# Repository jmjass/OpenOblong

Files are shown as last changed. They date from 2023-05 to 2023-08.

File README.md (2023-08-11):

# OpenRectangleCubsMod
Custom PCBs for a RP2040 powered rectangle controller.

Modified version of https://github.com/Armastardo/OpenRectangle that decreases size of the PCB and changes button layout to accomodate.

Original Dimensions: 339.13mm x 141.22mm

Modified Dimensions: 282.7mm x 136.22mm

Case Dimensions: 296mm x 154.4mm (~11.65" x ~6.08")

(Thickness of the case varies based on thickness of acrylic layers)

## Part Links:

Case Standoffs: 

https://www.aliexpress.us/item/2251832708378430.html?gatewayAdapt=glo2usa4itemAdapt&_randl_shipto=US

Calculate the thickness of your case and order standoffs about 1mm shorter than the case.

Case Screws: 
https://www.amazon.com/dp/B0798227SK?psc=1&ref=ppx_yo2ov_dt_b_product_details

Any M2 screws will work, I got these because I wanted black ones that are flush with the case.

Acrylic:

https://houstonacrylic.com/

There is a huge variety of colors and different designs of acrylic offered by these guys but they are a bit more expensive than other places. Also I had to pay about $17 for shipping so be sure to account for shipping costs in budget. If you order a 12 x 19 inch sheet from here you are able to cut 3 layers out of it.

If you are trying to make it as cheap as possible, I would recommend shopping around for clear acrylic because clear seemed to be the cheapest when I was looking. Here are a couple different thickness ones from amazon that I found:

1/8" For Top/Bottom Layers + PCB Layers on Aluminum Switchplate Design: https://www.amazon.com/dp/B09XR8NB28?psc=1&ref=ppx_yo2ov_dt_b_product_details

Acrylic Switchplate (.06"): https://www.amazon.com/dp/B09LTYDYKP?psc=1&ref=ppx_yo2ov_dt_b_product_details

PCB Layer/Hotswap Cutout Layer on Acylic Switchplate Design (.08"): https://www.amazon.com/dp/B09N3PN8PG?ref=ppx_yo2ov_dt_b_product_details&th=1

I recommend doing some searching on your own as there may be different options that are cheaper. 8" x 12" works the best for cutting 1 panel per sheet and for getting mroe than 1 panel per sheet you need multiples of 6.315" x 12". For example, 12" x 19" can get you 3 layers with very little margin of error or 12" x 21" would get you 3 layers way more comfortable although you are unlikely to find this size and would more commonly find 12" x 24"

3.5mm M1.6 PCB Standoffs:

https://www.ebay.com/itm/185215966272?var=692974532230

3mm M1.6 PCB Screws:

https://www.ebay.com/itm/183908369734

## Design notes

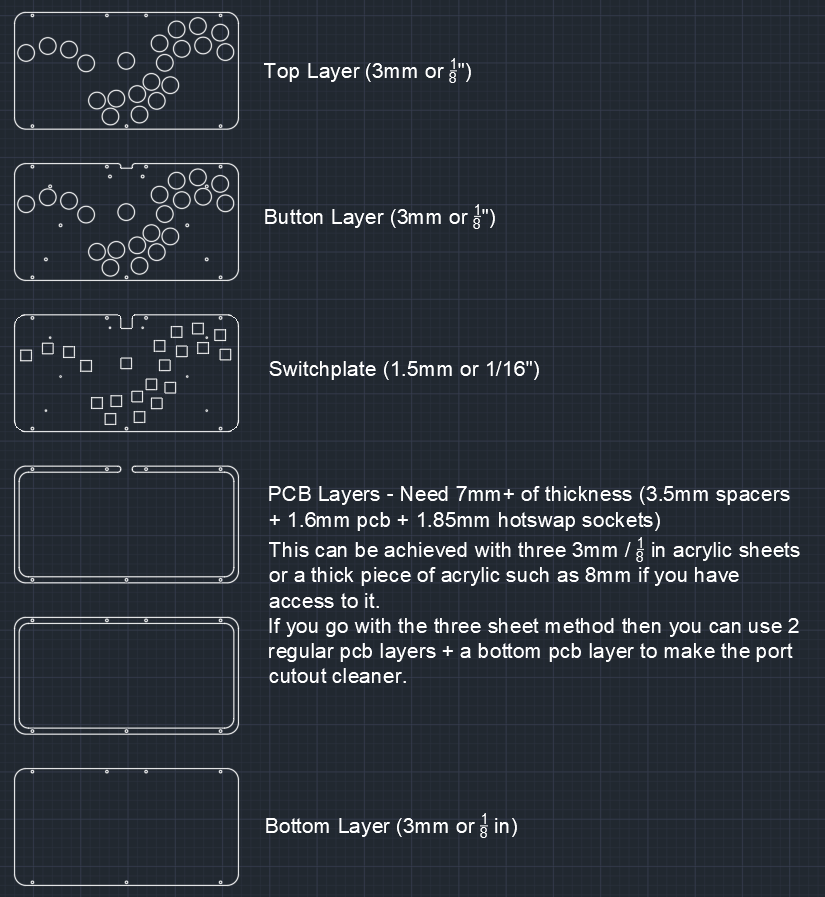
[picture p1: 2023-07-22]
CubsCase/ExpandedCase.png

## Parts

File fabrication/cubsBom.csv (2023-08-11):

Comment | Designator | Footprint | LCSC Part #
1uF | C1,C2,C4,C10 | Capacitor_SMD:C_0402_1005Metric | C52923
100nF | C3,C5,C6,C11,C12,C13,C14,C15,C16,C17 | Capacitor_SMD:C_0402_1005Metric | C1525
10uF | C9 | Capacitor_SMD:C_0402_1005Metric | C15525
22pF | C7,C8 | Capacitor_SMD:C_0402_1005Metric | C1555
Schottky Diode | D1,D2 | qw-footprints:CUSTOM D_SOD-123 | C8598
Fuse_Small | F1 | Fuse:Fuse_1206_3216Metric | C70069
USB C Connector | J1 | qw-footprints:TYPE-C_24P_QCHT | C456013
1M | R1 | Resistor_SMD:R_0603_1608Metric | C22935
5.1k | R2,R3 | Resistor_SMD:R_0402_1005Metric | C23186
5.6k | R5 | Resistor_SMD:R_0603_1608Metric | C23189
10k 0603 | R6 | Resistor_SMD:R_0603_1608Metric | C25804
10k 0402 | R4, R7 | Resistor_SMD:R_0402_1005Metric | C25744
27 | R8,R9 | Resistor_SMD:R_0603_1608Metric | C25190
1k | R10,R11 | Resistor_SMD:R_0402_1005Metric | C11702
Boot | SW1 | Button_Switch_SMD:SW_SPST_SKQG_WithStem | C318884
XC6206 | U1 | Package_TO_SOT_SMD:SOT-23 | C5446
USBLC6-2SC6 | U2 | Package_TO_SOT_SMD:SOT-23-6 | C5261088
RP2040 | U3 | qw-footprints:RP2040-QFN-56 | C2040
W25Q128JVS | U4 | Package_SO:SOIC-8_5.23x5.23mm_P1.27mm | C97521
12MHz | Y1 | Crystal:Crystal_SMD_3225-4Pin_3.2x2.5mm | C9002
PICO_LED | D3 | LED_SMD:LED_0805_2012Metric | C34499

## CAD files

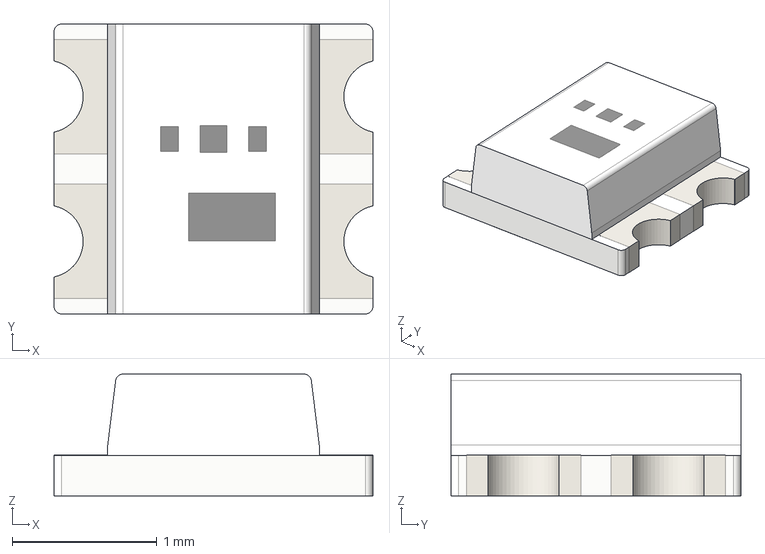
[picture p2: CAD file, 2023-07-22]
PCB Files/OpenOblong/marbastlib/3d/LED_WS2812_2020.step
2.20 x 2.00 x 0.842 mm

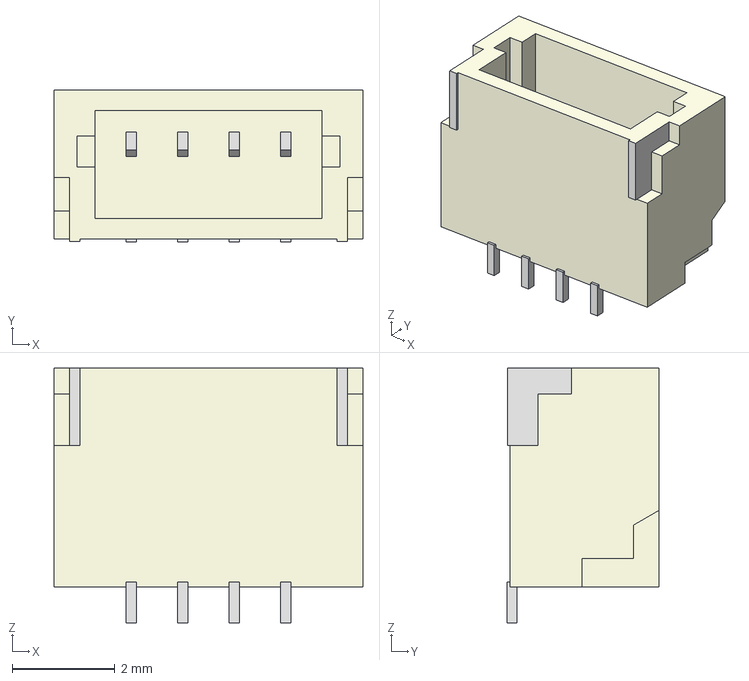
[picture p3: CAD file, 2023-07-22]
PCB Files/OpenOblongChocs/marbastlib/3d/CON_SM04B-SRSS-TB.step
6.00 x 2.96 x 4.95 mm

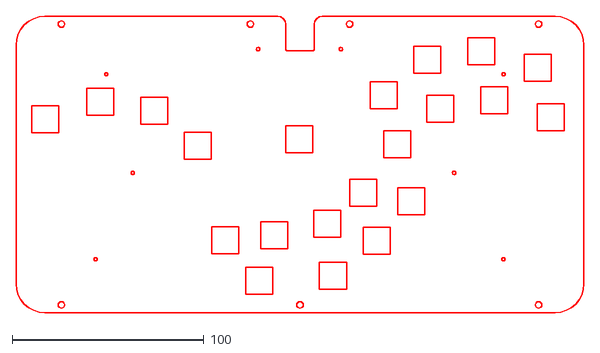
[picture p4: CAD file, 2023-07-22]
CubsCase/SwitchPlate14.1.dxf
296.0 x 154.4

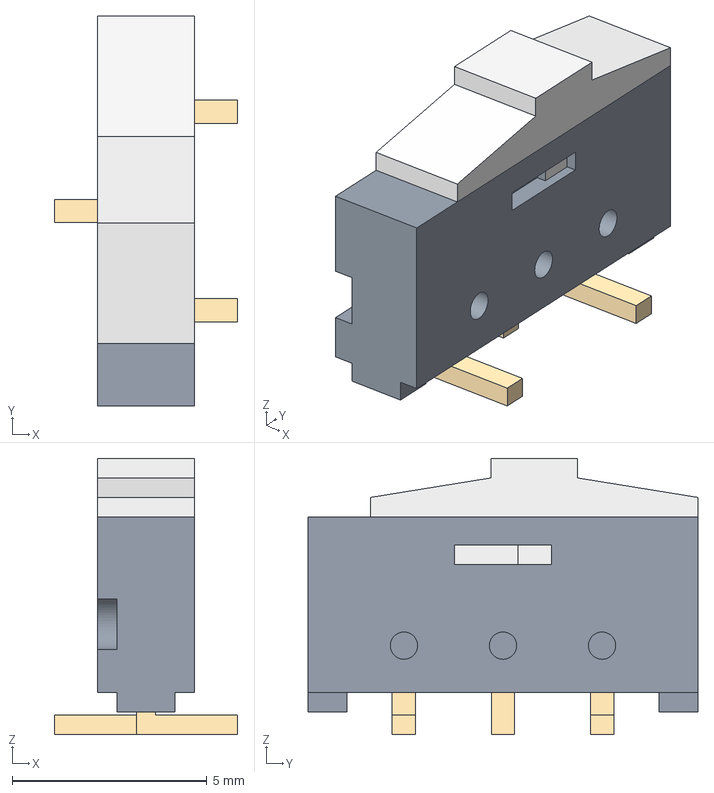
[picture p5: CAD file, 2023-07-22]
PCB Files/OpenOblong/marbastlib/3d/SW_ESP3020.step
4.70 x 10.0 x 7.08 mm

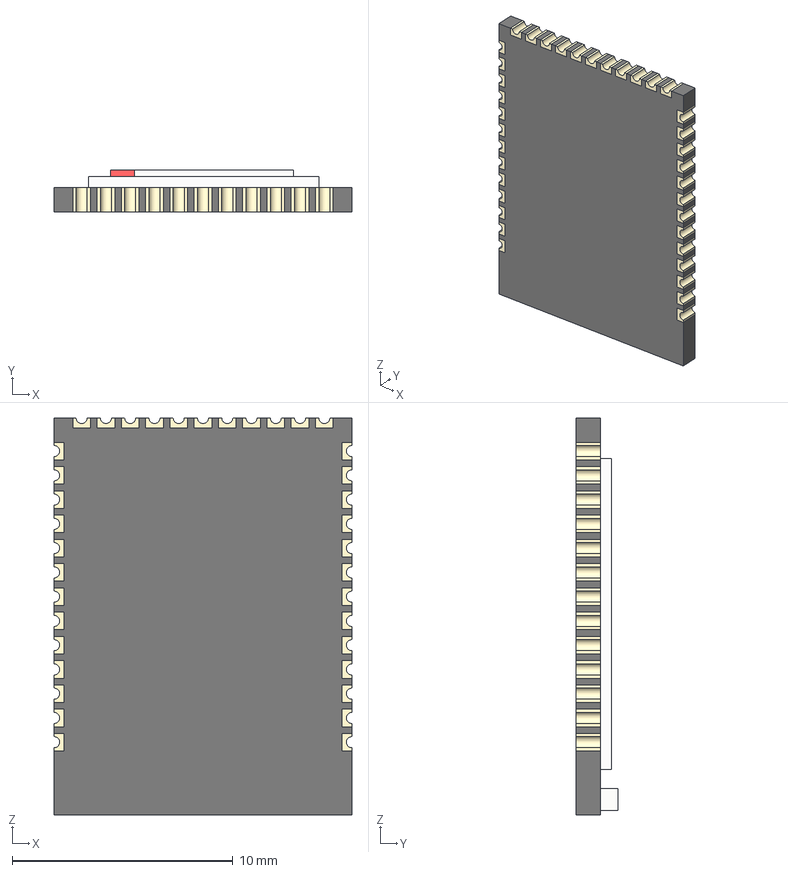
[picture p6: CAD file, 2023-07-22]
PCB Files/OpenOblongChocs/marbastlib/3d/holyiot_18010_nRF52840.step
13.5 x 1.92 x 18.0 mm

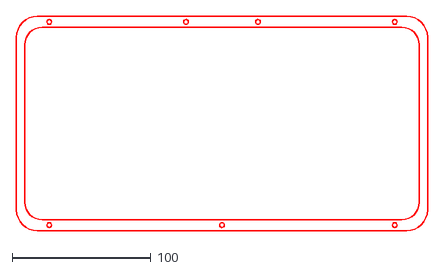
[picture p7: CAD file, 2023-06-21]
CubsCase/BottomPCBLayer.dxf
296.0 x 154.4

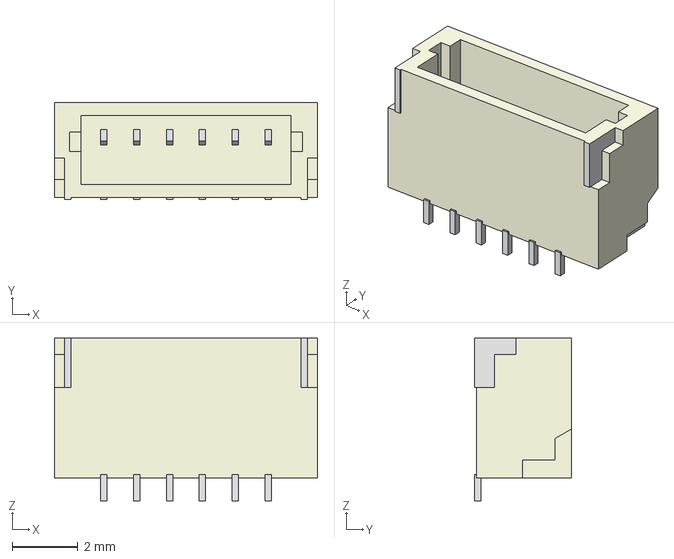
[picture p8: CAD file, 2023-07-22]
PCB Files/OpenOblongChocs/marbastlib/3d/CON_SM06B-SRSS-TB.step
8.00 x 2.96 x 4.95 mm

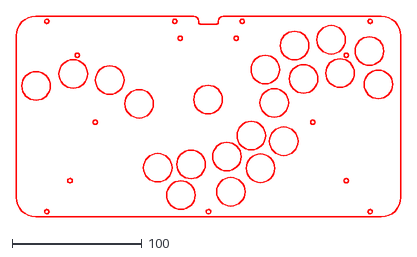
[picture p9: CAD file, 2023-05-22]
CubsCase/topLayer.dxf
296.0 x 154.4

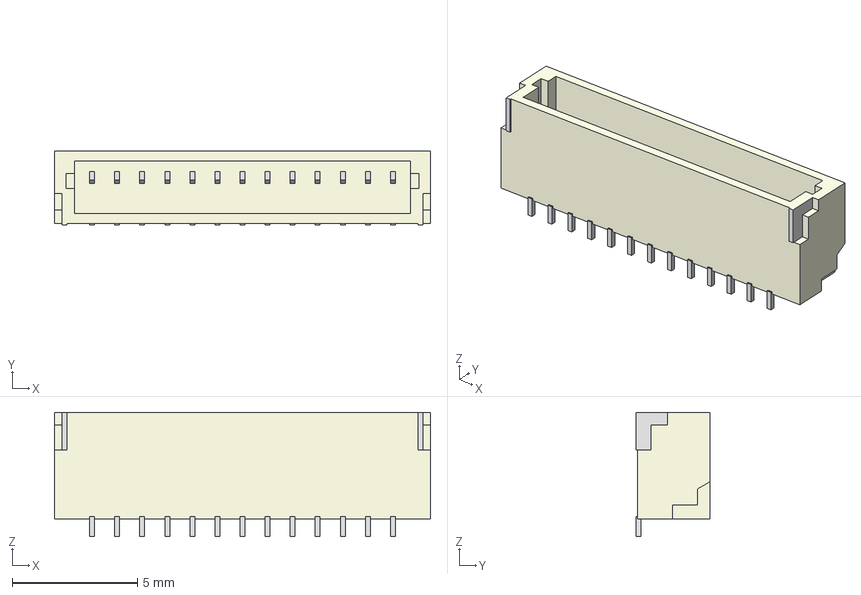
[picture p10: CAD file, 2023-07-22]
PCB Files/OpenOblong/marbastlib/3d/CON_SM13B-SRSS-TB.step
15.0 x 2.96 x 4.95 mm

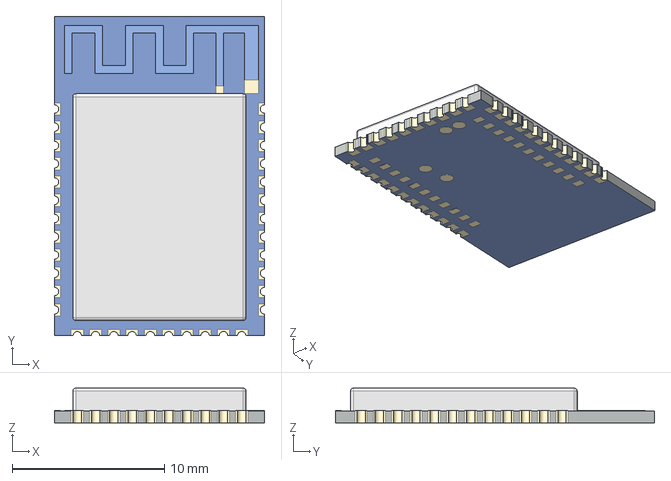
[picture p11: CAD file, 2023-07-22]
PCB Files/OpenOblongChocs/marbastlib/3d/moko_mk08a_nRF52840.step
13.8 x 21.0 x 2.29 mm

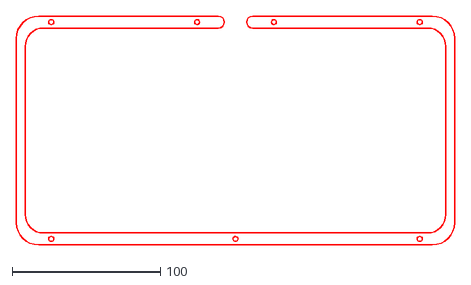
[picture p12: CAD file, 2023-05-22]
CubsCase/pcbLayer.dxf
296.0 x 154.4

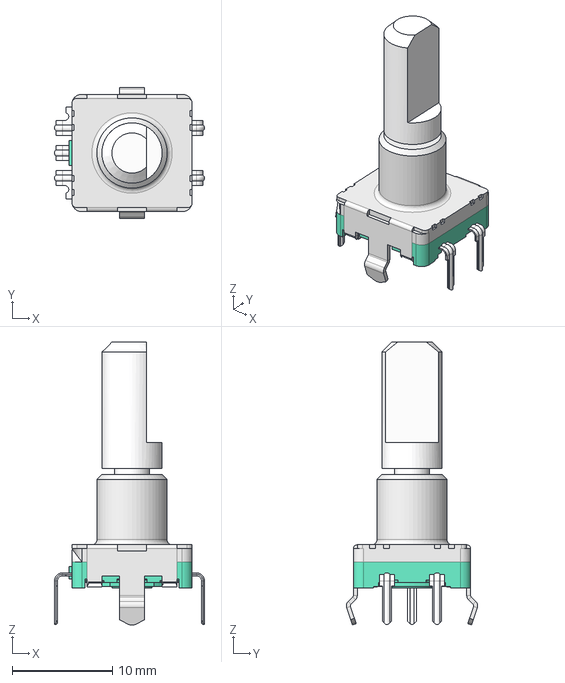
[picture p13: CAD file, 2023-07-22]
PCB Files/OpenOblong/marbastlib/3d/ROT_EC11E.step
14.9 x 13.1 x 28.2 mm

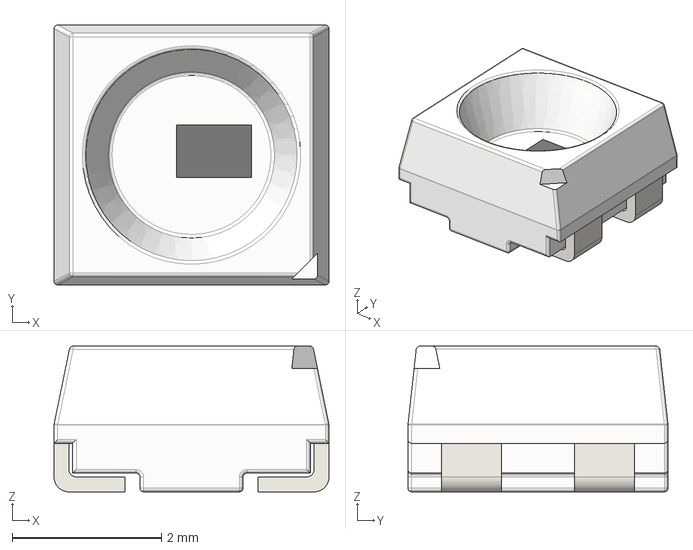
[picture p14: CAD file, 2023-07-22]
PCB Files/OpenOblongChocs/marbastlib/3d/LED_WS2812B-MINI.step
3.68 x 3.48 x 1.95 mm

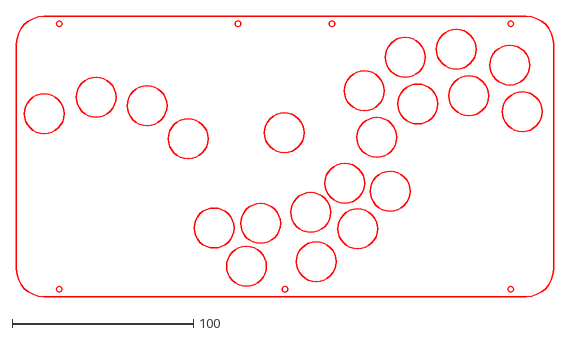
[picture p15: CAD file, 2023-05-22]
CubsCase/TopTop.dxf
296.0 x 154.4

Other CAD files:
CubsCase/expandedcase.dwg
CubsCase/LaserPrinting/SwitchPlateSpacerLayer.dwg
PCB Files/OpenOblong/marbastlib/3d/SW_SKHLLC.step
CubsCase/BottomLayer.dwg
CubsCase/BottomLayer.dxf
CubsCase/BottomPCBLayer.dwg
CubsCase/SwitchPlate14.1.dwg
CubsCase/TopTop.dwg
CubsCase/baseLayer.dxf
CubsCase/pcbLayer.dwg
CubsCase/topLayer.dwg
PCB Files/OpenOblong/marbastlib/3d/CON_BM02B-ACHSS.step
PCB Files/OpenOblong/marbastlib/3d/CON_MJ-4PP-9.step
PCB Files/OpenOblong/marbastlib/3d/CON_SM02B-SRSS-TB.step
PCB Files/OpenOblong/marbastlib/3d/CON_SM05B-SRSS-TB.step
PCB Files/OpenOblong/marbastlib/3d/CON_SM07B-SRSS-TB.step
PCB Files/OpenOblong/marbastlib/3d/CON_SM08B-SRSS-TB.step
PCB Files/OpenOblong/marbastlib/3d/CON_TYPE-C-31-M-12.step
PCB Files/OpenOblong/marbastlib/3d/CON_TYPE-C-31-M-14.step
PCB Files/OpenOblong/marbastlib/3d/Crystal_FA-128.step
PCB Files/OpenOblong/marbastlib/3d/HS_Kailh_Choc.step
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

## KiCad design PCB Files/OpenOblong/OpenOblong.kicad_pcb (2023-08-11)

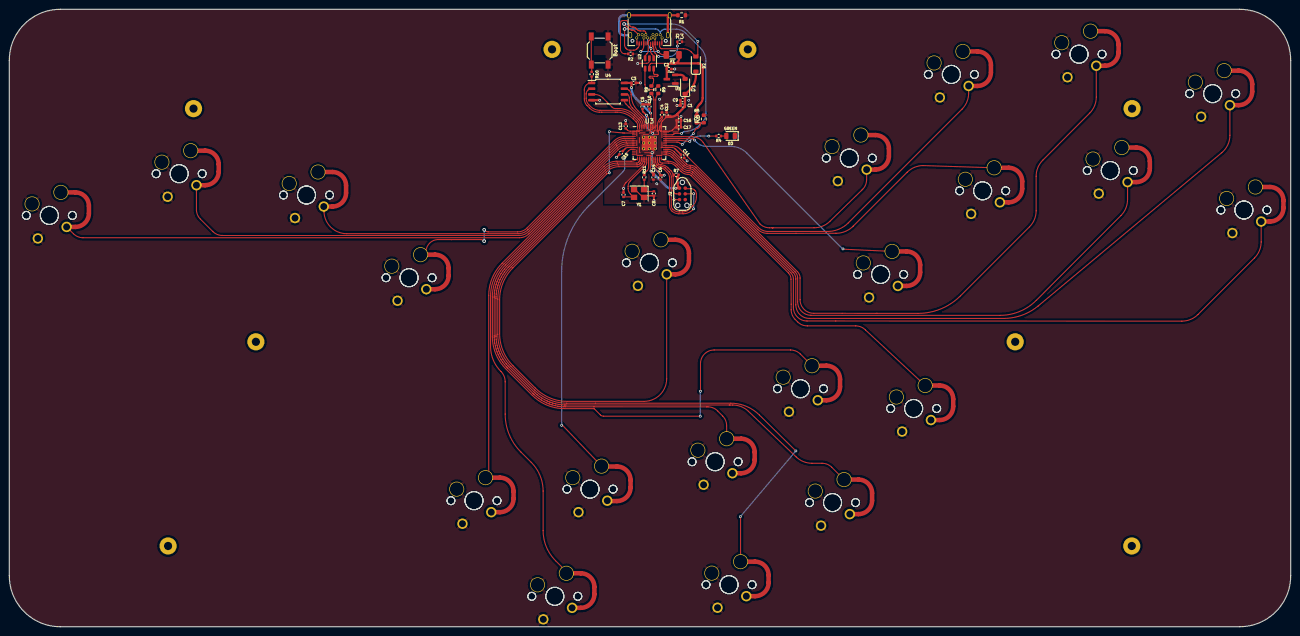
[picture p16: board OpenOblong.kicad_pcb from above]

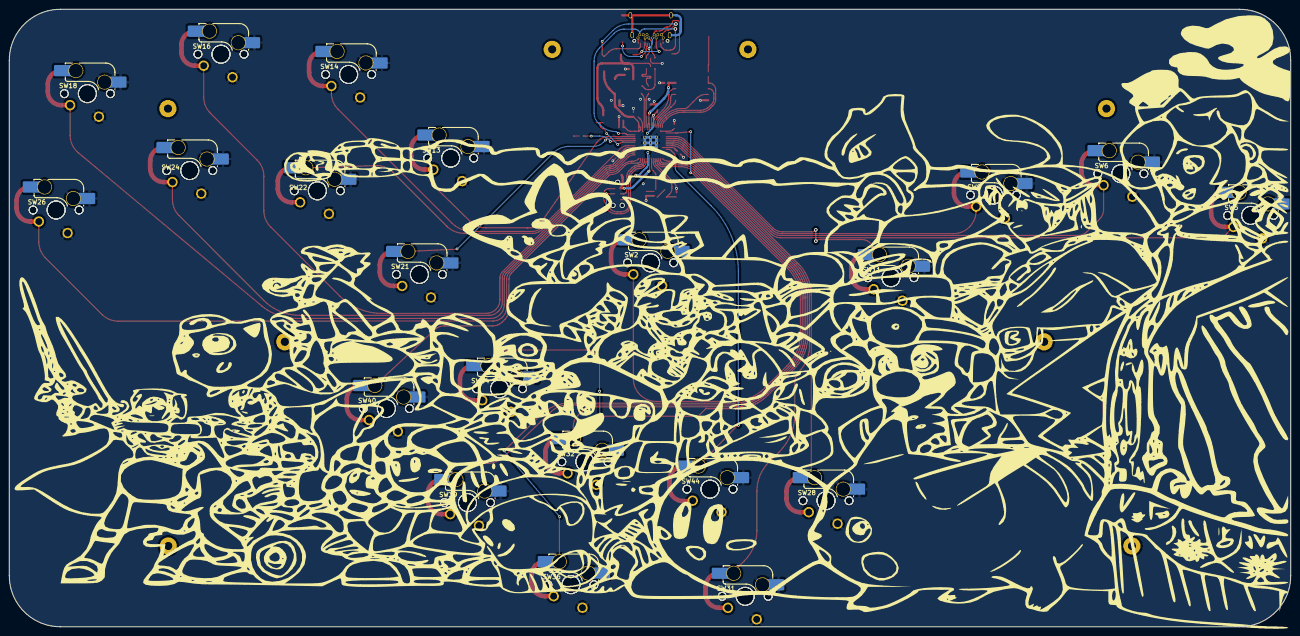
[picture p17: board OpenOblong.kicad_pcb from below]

Board: 2 copper layers, 282.7 x 136.2 mm, 90 parts (21 on the bottom side), 54 nets.

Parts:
C1, C2, C4, C10: 1uF; C_0402_1005Metric
C3, C5, C6, C11, C12, C13, C14, C15, C16, C17: 100nF; C_0402_1005Metric
C7, C8: 22pF; C_0402_1005Metric
C9: 10uF; C_0402_1005Metric
D1, D2: Schottky Diode; CUSTOM D_SOD-123
D3: GREEN; LED_0805_2012Metric
F1: 500 mA; Fuse_1206_3216Metric
H4, H5, H6, H7, H8, H9, H10, H11: MountingHole; MountingHole_2.2mm_M2_ISO14580_Pad
J1: USB C Connector; TYPE-C_24P_QCHT
J2: JTAG_TC2030; CON_TC2030_outlined
R1: 1M; R_0603_1608Metric
R2, R3: 5.1k; R_0402_1005Metric
R4, R7: 10k; R_0402_1005Metric
R5: 5.6k; R_0603_1608Metric
R6: 10k; R_0603_1608Metric
R8, R9: 27; R_0603_1608Metric
R10, R11: 1k; R_0402_1005Metric
SW1: Boot; SW_SPST_SKQG_WithStem
SW2, SW5, SW6, SW9, SW11, SW13, SW14, SW16, SW18, SW21, SW22, SW24, SW26, SW28, SW31, SW32, SW34, SW36, SW39, SW40, SW44: MX_SW_HS; SW_MX_HS_1u
SW3, SW4, SW7, SW8, SW10, SW12, SW15, SW17, SW19, SW20, SW23, SW25, SW27, SW29, SW30, SW33, SW35, SW37, SW38, SW41, SW45: MX_SW_solder; SW_MX_1u
U1: XC6206; SOT-23
U2: USBLC6-2SC6; SOT-23-6
U3: RP2040; RP2040-QFN-56
U4: W25Q128JVS; SOIC-8_5.23x5.23mm_P1.27mm
Y1: 12MHz; Crystal_SMD_3225-4Pin_3.2x2.5mm

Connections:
3vCable: D2.2 (A), J1.A2 (TX1+), J1.B2 (TX2+)
+1V1: C4.1, C5.1, C6.1, U3.23 (DVDD), U3.45 (VREG_VOUT), U3.50 (DVDD)
+3V3: C1.2, C3.1, C9.1, C10.1, C11.1, C12.1, C13.1, C14.1, C15.1, C16.1, C17.1, D1.1 (K), D2.1 (K), J2.1 (VCC), R7.1, U3.1 (IOVDD), U3.10 (IOVDD), U3.22 (IOVDD), U3.33 (IOVDD), U3.42 (IOVDD), U3.43 (ADC_AVDD), U3.44 (VREG_VIN), U3.48 (USB_VDD), U3.49 (IOVDD), U4.8 (VCC)
+5V: C2.2, F1.2, R5.1, U1.3 (VI), U2.5 (VBUS)
/D_+: R8.2, U3.47 (D+)
/D_-: R9.2, U3.46 (D-)
/XTAL_O: C8.2, R11.1, Y1.1
/~USB_BOOT: R10.1, SW1.2
A: SW38.1, SW39.2, U3.17 (GPIO14)
B: SW20.1, SW21.2, U3.38 (GPIO26/ADC0)
CS: R10.2, U3.56 (QSPI_SS_N), U4.1 (~CS)
C_DN: SW36.2, SW37.1, U3.18 (GPIO15)
C_LT: SW32.2, SW33.1, U3.16 (GPIO13)
C_RT: SW40.2, SW41.1, U3.27 (GPIO16)
C_UP: SW34.2, SW35.1, U3.15 (GPIO12)
D+: R8.1, U2.6 (I/O1)
D-: R9.1, U2.4 (I/O2)
DATA: J1.A11 (RX2+), J1.B11 (RX1+), U3.40 (GPIO28/ADC2)
DBUS+: J1.A6 (D+), J1.B6 (D+), U2.1 (I/O1)
DBUS-: J1.A7 (D-), J1.B7 (D-), U2.3 (I/O2)
DOWN: SW8.1, SW9.2, U3.5 (GPIO3)
GND: C1.1, C2.1, C3.2, C4.2, C5.2, C6.2, C7.1, C8.1, C9.2, C10.2, C11.2, C12.2, C13.2, C14.2, C15.2, C16.2, C17.2, D3.1 (K), J1.A1 (GND), J1.A12 (GND), J1.B1 (GND), J1.B12 (GND), J2.5 (GND), R1.1, R2.1, R3.2, R6.2, SW1.1, SW2.1, SW3.2, SW4.2, SW5.1, SW6.1, SW7.2, SW8.2, SW9.1, SW10.2, SW11.1, SW12.2, SW13.1, SW14.1, SW15.2, SW16.1, SW17.2, SW18.1, SW19.2, SW20.2, SW21.1, SW22.1, SW23.2, SW24.1, SW25.2, SW26.1, SW27.2, SW28.1, SW29.2, SW30.2, SW31.1, SW32.1, SW33.2, SW34.1, SW35.2, SW36.1, SW37.2, SW38.2, SW39.1, SW40.1, SW41.2, SW44.1, SW45.2, U1.1 (GND), U2.2 (GND), U3.19 (TESTEN), U3.57 (GND), U4.4 (GND), Y1.2, Y1.4
L: SW4.1, SW5.2, U3.7 (GPIO5)
LEFT: SW6.2, SW7.1, U3.6 (GPIO4)
LS: SW16.2, SW17.1, U3.31 (GPIO20)
M1: SW28.2, SW29.1, U3.8 (GPIO6)
M2: SW30.1, SW31.2, U3.9 (GPIO7)
M3: SW44.2, SW45.1, U3.11 (GPIO8)
MS: SW18.2, SW19.1, U3.29 (GPIO18)
unnamed: D1.2 (A), U1.2 (VO)
unnamed: D3.2 (A), R4.2
unnamed: F1.1, J1.A4 (VBUS), J1.A9 (VBUS), J1.B4 (VBUS), J1.B9 (VBUS)
unnamed: J1.A5 (CC1), R3.1
unnamed: J1.B5 (CC2), R2.2
unnamed: J1.S1 (SHIELD), R1.2
PICO_LED: R4.1, U3.37 (GPIO25)
QSPI_CLK: U3.52 (QSPI_SCLK), U4.6 (CLK)
R: SW12.1, SW13.2, U3.39 (GPIO27/ADC1)
RIGHT: SW10.1, SW11.2, U3.4 (GPIO2)
SD0: U3.53 (QSPI_SD0), U4.5 (DI(IO0))
SD1: U3.55 (QSPI_SD1), U4.2 (DO(IO1))
SD2: U3.54 (QSPI_SD2), U4.3 (IO2)
SD3: U3.51 (QSPI_SD3), U4.7 (IO3)
START: SW2.2, SW3.1, U3.2 (GPIO0)
SWCLK: J2.4 (SWCLK), U3.24 (SWCLK)
SWD: J2.2 (SWDIO), U3.25 (SWDIO)
UP: SW26.2, SW27.1, U3.28 (GPIO17)
VBUS_SENSE: R5.2, R6.1, U3.36 (GPIO24)
X: SW22.2, SW23.1, U3.32 (GPIO21)
XTAL_IN: C7.2, U3.20 (XTAL_IN), Y1.3
XTAL_OUT: R11.2, U3.21 (XTAL_OUT)
Y: SW14.2, SW15.1, U3.34 (GPIO22)
Z: SW24.2, SW25.1, U3.30 (GPIO19)
~RESET: J2.3 (~RST), R7.2, U3.26 (~RUN)

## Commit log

2023-03-15 modified OpenRectangle design
    Modified OpenRectangle design to make it smaller and change button positions
    [ExplodedOpenRectangleV2.1PCB.dwg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]
2023-03-15 updated case folders
    [ExplodedOpenRectangleV2.1PCB.dwg, OpenRectangle.kicad_pcb, OpenRectangleNewCase.dwg]
2023-03-15 updated case diagram
    [expandedcase.dwg]
2023-03-15 fixed pcb layer thickness
    [expandedcase.dwg]
2023-03-16 updated mounting hole size
    [OpenRectangle-B_Cu.gbl, OpenRectangle-B_Mask.gbs, OpenRectangle-B_Paste.gbp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]
2023-03-16 edited case and added annotations to expanded
    [OpenRectangle-F_Courtyard.dxf, OpenRectangle.kicad_pcb, baseLayer.dwg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]
2023-03-16 updated fabrication files
    [OpenRectangle-B_Cu.gbl, OpenRectangle-B_Mask.gbs, OpenRectangle-B_Paste.gbp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]
2023-03-17 updated case
    [19x12-3panel.dwg, OpenRectangle.kicad_pcb, PCBLayerSideBySide.dwg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]
2023-03-17 generated new gerbers
    [OpenRectangle-B_Cu.gbl, OpenRectangle-B_Mask.gbs, OpenRectangle-B_Paste.gbp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]
2023-03-17 updated BOM
    [OpenRectangle.csv, OpenRectangle.kicad_pcb, cubsBom.csv]
2023-03-18 updated case to make PCB layer walls bigger
    [PCBLayerSideBySide.dwg, TopLayerPrint.dwg, baseLayer.dwg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]
2023-03-22 edited case and added laser cut files
    [19x12-3panel.dwg, BottomLayer.dwg, BottomLayer.dxf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]
2023-03-23 added picture of alternate case version
2023-03-23 updated case holes to fit aliexpress standoffs
    [BottomLayer.dwg, BottomLayer.dxf, HotswapCutoutsLayer.dwg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]
2023-03-23 updated laser printing files
    [BottomLayer.dwg, HotswapCutoutsLayer.dwg, PCBAndBottomNonSpaced.dwg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]
2023-04-12 revamped case
    [2PCBHotswap.dxf, 2TopBot.dxf, 3Switchplate.dxf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]
2023-04-20 Added optional buttons
    [Buttons.kicad_sch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]
2023-05-22 updated pinout to default haybox and revised case
    [1Bot1Hot.dwg, 1Bot1Hot.dxf, 2PCBHot.dwg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]
2023-05-26 updated casse
    [1Bot1Hot.dwg, 1Bot1Hot.dxf, 2TopBot.dwg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]
2023-06-21 added BottomPCBLayer
    [2PCBBotPCB.dwg, 2PCBBotPCB.dxf, BottomPCBLayer.dwg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]
2023-07-22 updated board and case
    [1Bot1Hot.dwg, 1Bot1Hot.dxf, 2PCBBotPCB.dwg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]
2023-08-11 changed c-up wiring
    [OpenOblong-B_Cu.gbl, OpenOblong-B_Mask.gbs, OpenOblong-B_Paste.gbp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]
